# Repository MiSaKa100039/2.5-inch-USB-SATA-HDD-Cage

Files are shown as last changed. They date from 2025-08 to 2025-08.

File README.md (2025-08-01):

# ***2.5寸USB-SATA硬盘笼***

## <u>视频链接:[B站视频--功能演示及介绍](https://www.bilibili.com/video/BV1YCw5eoERG/?vd_source=5028cf5016d7ed990ad38551eb4883cf)</u>

## 项目简介:

本项目采用JMS578作为usb-sata桥,JMB575端口倍增的方案,实现usb到多个sata硬盘的通信

## 项目参数:

DC12v电源输入,jms578内置3.3v的ldo和buck控制器,因此只需考虑jmb575的3.3v和1.2v电压供电.
12v输入进来后通过tps54335a降压到5v,再使用mp9148双路buck降压输出3.3和1.2给jmb575供电

但是考虑到tps54335a的封装有点不好焊接,隧将其改为了中兴zxdn10的电源模块
和主机间连接采用Type-B接口,相对来说更为牢固.接口速度为USB3.0 5Gpbs,但是usb后面级联sata的方案对于硬盘的随机读写性能有较大的损失,所以对此在意的可以考虑其他方案(机械硬盘用户无视此条)







## 注意事项

1.在usb接口和dc电源接口的地方,请用钳子剪掉突出来的引脚,避免接触到硬盘.
2.先焊接电源部分,上电电压正常后再焊接芯片,以免烧毁芯片
3.jms578的晶振为30mhz,jmb575为25mhz
4.固件默认休眠时间为10min,若需更长时间或者关闭休眠,可以使用附件中的软件修改
5.由于最后一次修改工程后没能保存,所以附件中的ib0m和实际有区别,就是风扇接口位置不同.
6.电源功率的大小取决于你的硬盘功率
7.flash大部分都兼容,不确定就买p25d40h,便宜好用.



## 组装流程

背后的散热风扇为12v5010的风扇,主板上有一颗电阻位,可以选择合适大小的电阻来调节风扇转速,一般情况下直接短接即可



## 实物图

















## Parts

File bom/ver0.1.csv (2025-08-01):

Comment | Description | Designator | Footprint | LibRef | Pins | Quantity | 编号
10uF |  | C1, C8, C15, C16, C19, C20, C40 | Capacitor_SMD:C_0603_1608Metric
0.1uF |  | C2, C9, C45 | Capacitor_SMD:C_0603_1608Metric
0.1uF |  | C3, C133 | Capacitor_SMD:C_0402_1005Metric
47uF |  | C4, C5, C13, C14 | Capacitor_SMD:C_0805_2012Metric
0.012uF |  | C6, C11 | Capacitor_SMD:C_0402_1005Metric
120pF |  | C7, C12 | Capacitor_SMD:C_0402_1005Metric
22uF |  | C17, C18 | Capacitor_SMD:C_0603_1608Metric
1uF |  | C21, C38, C57 | Capacitor_SMD:C_0402_1005Metric
33pF |  | C22, C31 | Capacitor_SMD:C_0603_1608Metric
100nF |  | C23, C24, C25, C26, C27, C28, C29, C30, C32, C33, C34, C46, C47, C50, C51, C52, C53, C54, C55, C56, C58, C59, C60, C61, C62, C63, C64, C65, C130, C131, C132 | Capacitor_SMD:C_0603_1608Metric
100nF |  | C35, C36 | Capacitor_SMD:C_0402_1005Metric
0R |  | C37, C39 | Capacitor_SMD:C_0402_1005Metric
10nF |  | C41, C42, C43, C44, C114, C115, C116, C117, C118, C119, C120, C121, C122, C123, C124, C125, C126, C127, C128, C129 | Capacitor_SMD:C_0402_1005Metric
25pF |  | C48, C49 | Capacitor_SMD:C_0603_1608Metric
270uF |  | C66, C67, C68, C69, C70, C71, C72, C73 | PCM_Capacitor_SMD_AKL:CP_Elec_6.3x5.4
220uF |  | C74, C75, C76, C77, C78, C79, C80, C81 | Capacitor_SMD:C_0805_2012Metric_Pad1.18x1.45mm_HandSolder
1uF |  | C82, C83, C84, C85, C86, C87, C88, C89 | Capacitor_SMD:C_0805_2012Metric_Pad1.18x1.45mm_HandSolder
100nF |  | C90, C91, C92, C93, C94, C95, C96, C97 | Capacitor_SMD:C_0805_2012Metric_Pad1.18x1.45mm_HandSolder
22uF |  | C98, C99, C100, C101, C102, C103, C104, C105 | PCM_Capacitor_SMD_AKL:CP_Elec_6.3x5.3
100uF |  | C106, C107, C108, C109, C110, C111, C112, C113 | Capacitor_SMD:C_0805_2012Metric_Pad1.18x1.45mm_HandSolder
LED |  | D1, D2, D3, D4, D5, D6, D7, D8 | LED_SMD:LED_0805_2012Metric
USB 3.1 B |  | J1 | Connector_USB:USB B 姣嶅骇 鐩寸珛
SWITCH |  | J2 | Connector_PinSocket_1.27mm:PinSocket_1x02_P1.27mm_Vertical
dc 5.5mm |  | J3 | Connector:DC socket 5.5mm
SATA纭洏鎻掑ご |  | J4, J5, J6, J7 | Connector_SATA_SAS:SATA 29pin smd
fan2 |  | J9 | Connector_PinSocket_1.27mm:PinSocket_1x02_P1.27mm_Vertical
~ |  | jmb1 | Package_DFN_QFN:QFN-64-1EP_9x9mm_P0.5mm_EP3.4x3.4mm_ThermalVias
15uH |  | L1, L2 | Inductor_SMD:L_Chilisin_BMRA00040420
1uH |  | L3 | Inductor_SMD:L_Chilisin_BMRA00040420
2uH |  | L4 | Inductor_SMD:L_Chilisin_BMRA00040420
4.7uH |  | L5 | Inductor_SMD:L_Chilisin_BMRA00040420
AO4407A |  | Q1, Q2 | PCM_4ms_Package_SOIC:SOIC-8_3.9x4.9mm_Pitch1.27mm
220k |  | R1, R8 | Resistor_SMD:R_0402_1005Metric
43.2K |  | R2, R9 | Resistor_SMD:R_0402_1005Metric
143K |  | R3, R10 | Resistor_SMD:R_0402_1005Metric
51.1R |  | R4, R12 | Resistor_SMD:R_0402_1005Metric
100k |  | R5, R13, R15, R21 | Resistor_SMD:R_0402_1005Metric
19.1K |  | R6, R14 | Resistor_SMD:R_0402_1005Metric
3.74K |  | R7, R11 | Resistor_SMD:R_0402_1005Metric
133k |  | R16, R22 | Resistor_SMD:R_0402_1005Metric
390k |  | R17 | Resistor_SMD:R_0402_1005Metric
402K |  | R18 | Resistor_SMD:R_0402_1005Metric
390K |  | R19 | Resistor_SMD:R_0402_1005Metric
88.7K |  | R20 | Resistor_SMD:R_0402_1005Metric
100K |  | R23 | Resistor_SMD:R_0402_1005Metric
330K |  | R24 | Resistor_SMD:R_0402_1005Metric
4.7K |  | R25, R29, R30, R31, R32 | Resistor_SMD:R_0402_1005Metric
12K |  | R26 | Resistor_SMD:R_0402_1005Metric
200R |  | R27 | Resistor_SMD:R_0603_1608Metric
12k |  | R28 | Resistor_SMD:R_0402_1005Metric
10k |  | R33 | Resistor_SMD:R_0402_1005Metric
4k |  | R34 | Resistor_SMD:R_0603_1608Metric
2k |  | R35, R36, R37, R38, R39, R40, R41, R42 | PCM_4ms_Resistor:R_0402
2k |  | R44 | PCM_4ms_Resistor:R_0603
T-BJT-NPN |  | T1 | Package_TO_SOT_SMD:SOT-23-3
TPS54335A |  | U1, U2 | Converter_DCDC:TPS54335ADRCR
~ |  | U3 | Package_TO_SOT_SMD:SOT-23-8
~ |  | U4, U6 | PCM_4ms_Package_SOIC:SOIC-8_3.9x4.9mm_Pitch1.27mm
~ |  | U5 | Package_DFN_QFN:QFN-48-1EP_6x6mm_P0.4mm_EP4.2x4.2mm_ThermalVias
Crystal_GND24_Small |  | Y1, Y2 | Crystal:Crystal_SMD_Abracon_ABM8AIG-4Pin_3.2x2.5mm

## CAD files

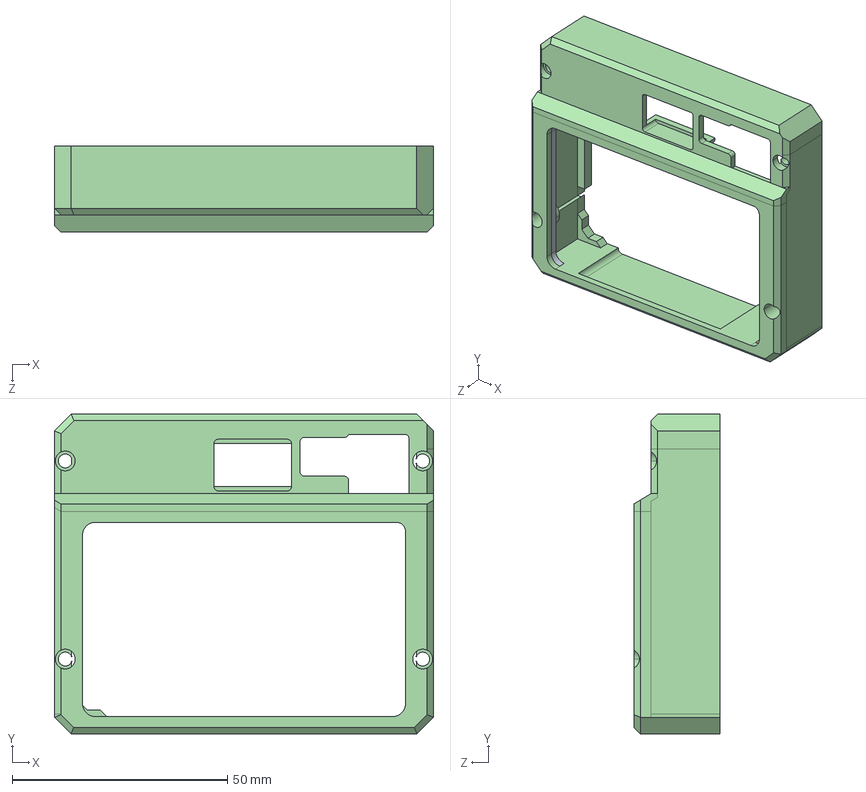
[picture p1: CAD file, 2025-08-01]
壳体/后盖v2.STEP
88.0 x 74.2 x 20.1 mm

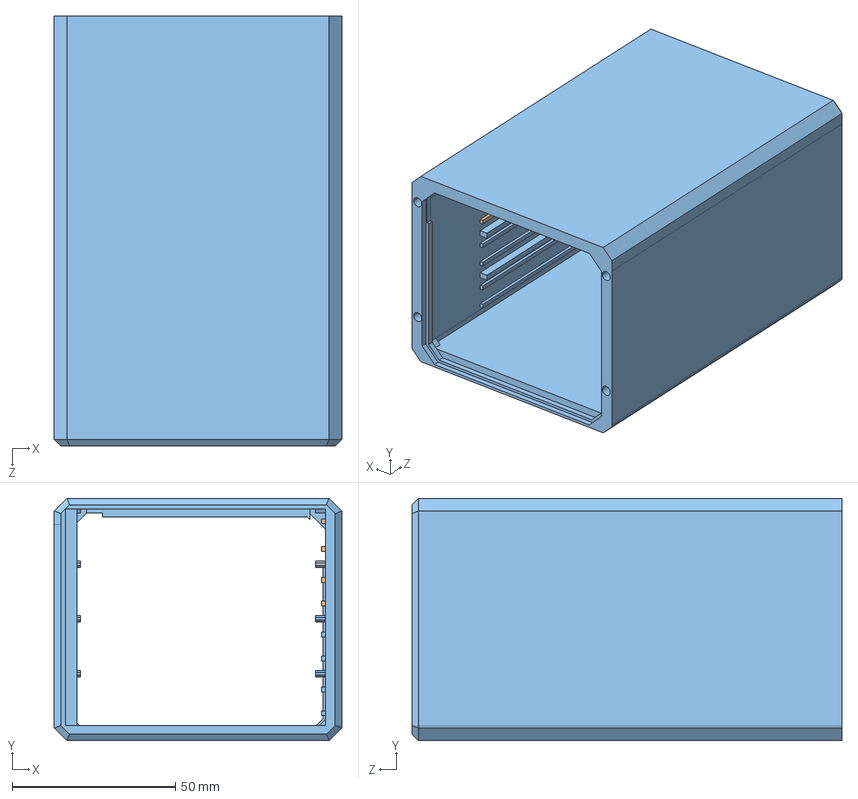
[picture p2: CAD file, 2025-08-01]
壳体/body.STEP
88.0 x 74.2 x 131.6 mm

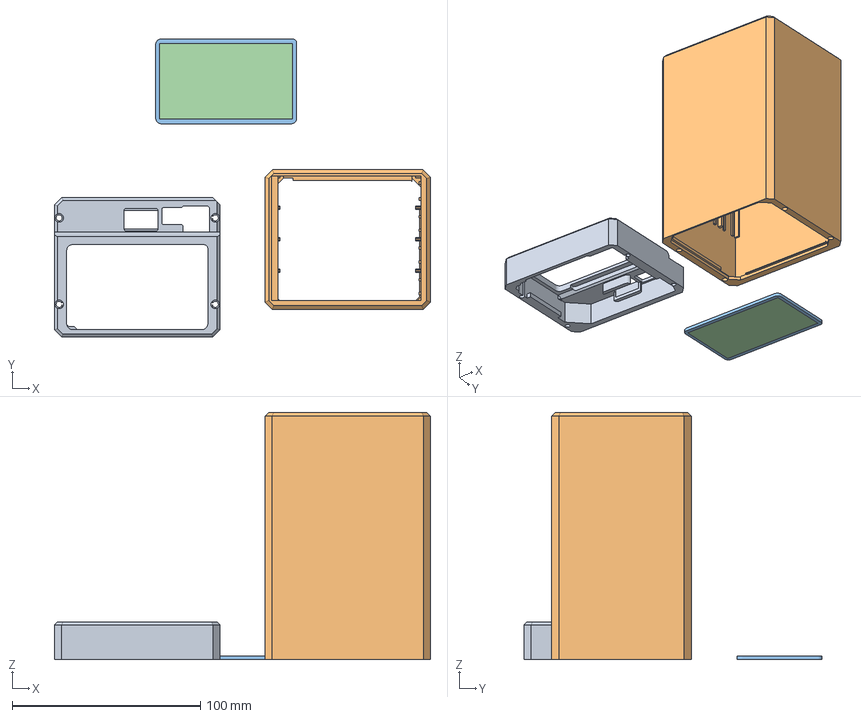
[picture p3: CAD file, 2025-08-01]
壳体/printer.3mf
199.9 x 158.5 x 131.6 mm
后盖v2.STEP
body.STEP
散热.STEP
立方体

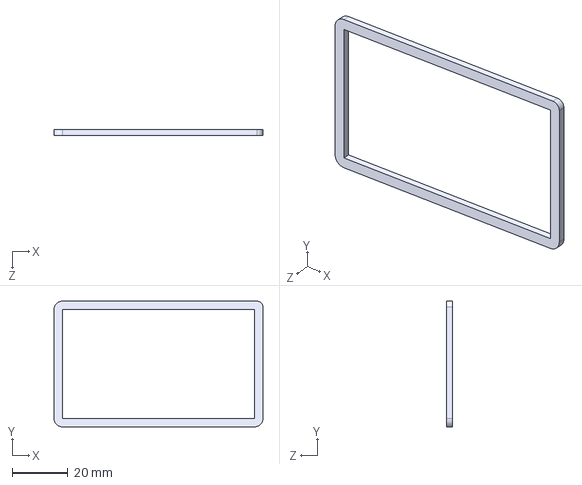
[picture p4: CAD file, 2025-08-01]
壳体/散热.STEP
75.0 x 45.1 x 2.00 mm

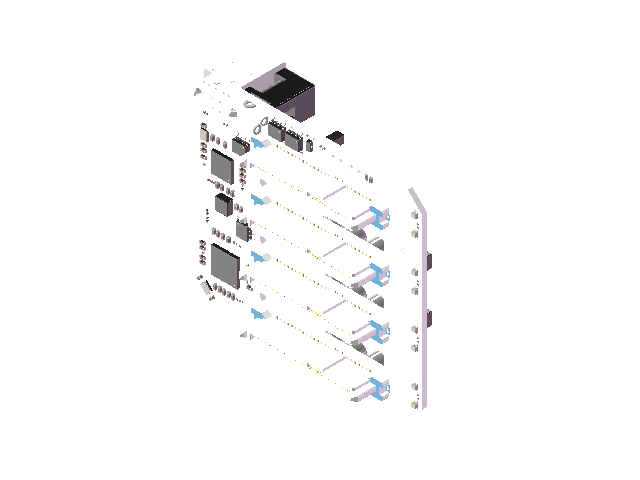
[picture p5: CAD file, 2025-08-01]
bord.SLDASM
SOLID.step x 42
SOLID-0.step x 8
SOLID-1.step x 8
SOLID-2.step x 47
SOLID-3.step x 33
SOLID-4.step x 4
SOLID-5.step
SOLID-6.step
SOLID-7.step
SOLID-8.step x 2
SOLID-9.step x 2
COMPOUND.step x 5
SOLID-10.step x 4
SOLID-11.step x 8
COMPOUND-12.step x 2
SOLID-13.step
SOLID-14.step x 8
COMPOUND-15.step
SOLID-16.step
COMPOUND-17.step
ver0.1 PCB.step

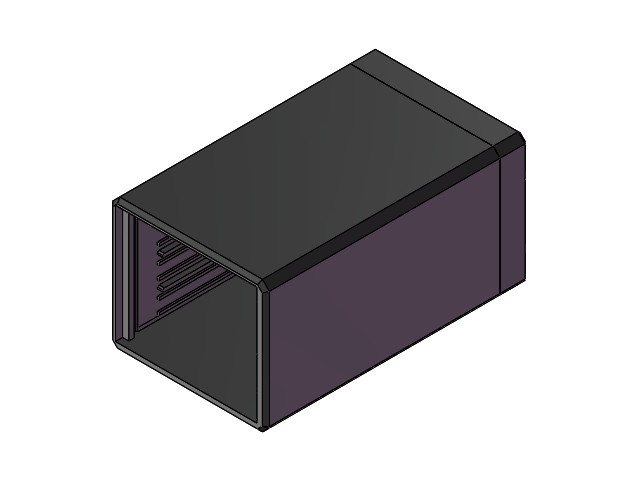
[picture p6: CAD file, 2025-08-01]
壳体/v0.1.SLDASM
零件1^装配体1
零件2^装配体1

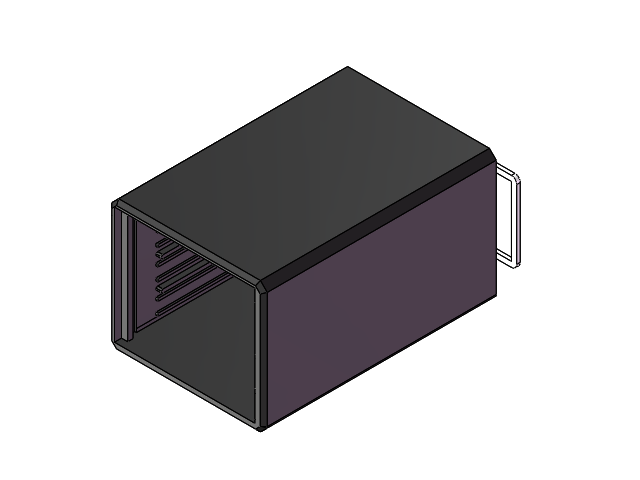
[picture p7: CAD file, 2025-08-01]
壳体/ve0.2.SLDASM
零件1^ve0.2
零件5^ve0.2

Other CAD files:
壳体/后盖.STEP

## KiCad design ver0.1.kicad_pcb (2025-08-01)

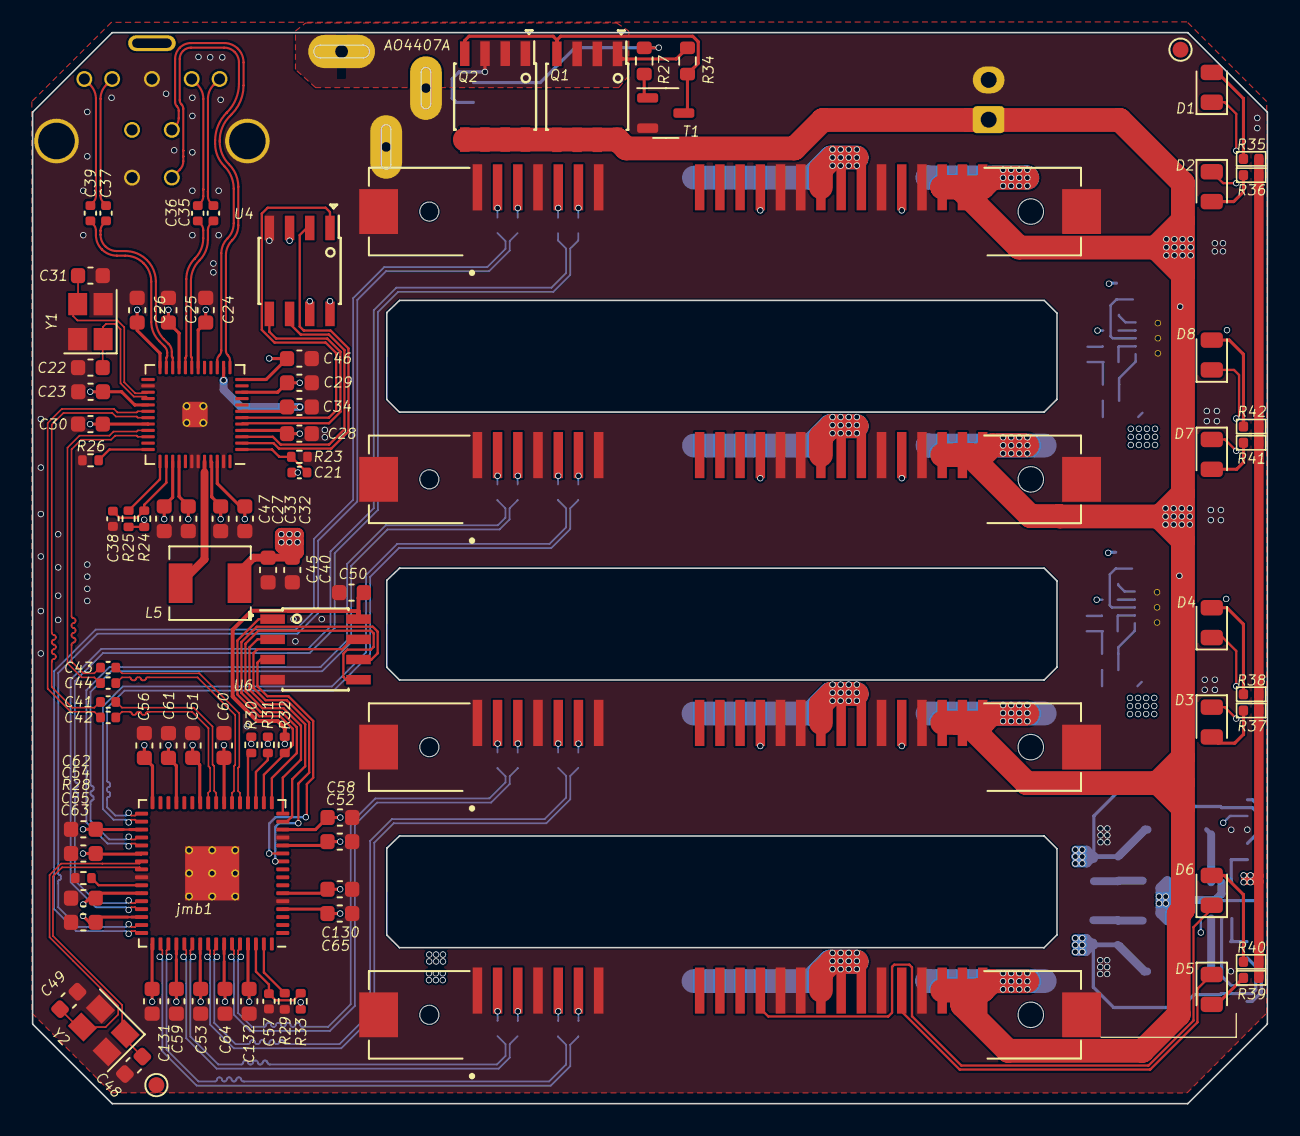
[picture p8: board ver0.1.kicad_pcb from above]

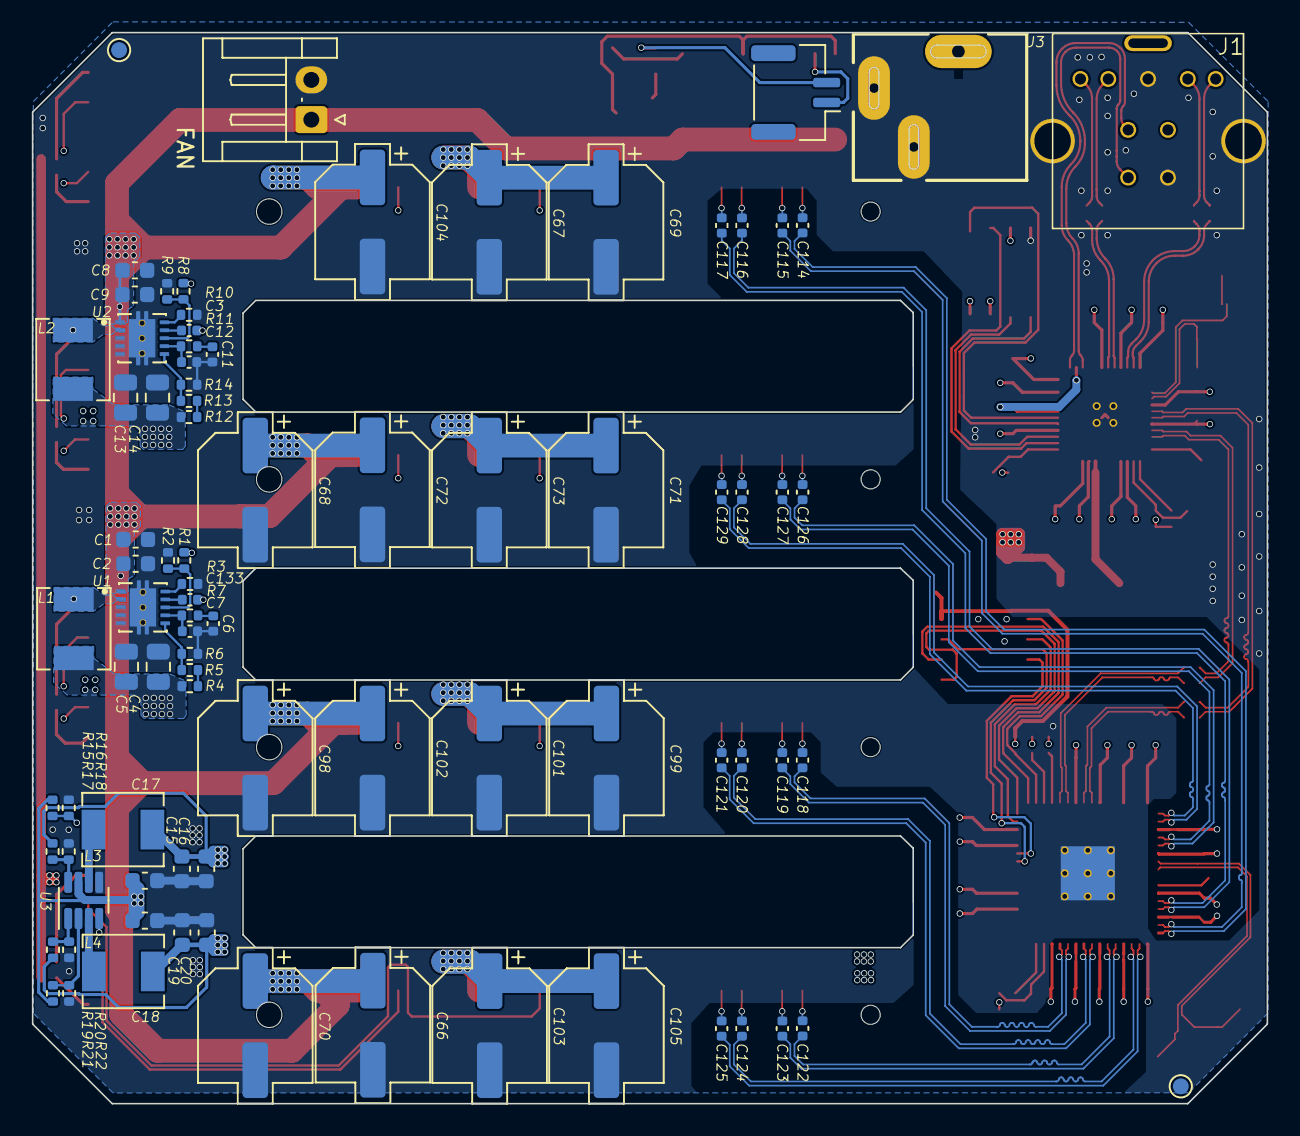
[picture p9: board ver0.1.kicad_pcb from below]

Board: 4 copper layers, 77.6 x 67.3 mm, 178 parts (86 on the bottom side), 124 nets.

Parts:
C1, C8, C15, C16, C19, C20, C40: 10uF; C_0603_1608Metric
C2, C9, C45: 0.1uF; C_0603_1608Metric
C3, C133: 0.1uF; C_0402_1005Metric
C4, C5, C13, C14: 47uF; C_0805_2012Metric
C6, C11: 0.012uF; C_0402_1005Metric
C7, C12: 120pF; C_0402_1005Metric
C17, C18: 22uF; C_0603_1608Metric
C21, C38, C57: 1uF; C_0402_1005Metric
C22, C31: 33pF; C_0603_1608Metric
C23, C24, C25, C26, C27, C28, C29, C30, C32, C33, C34, C46, C47, C50, C51, C52, C53, C54, C55, C56, C58, C59, C60, C61, C62, C63, C64, C65, C130, C131, C132: 100nF; C_0603_1608Metric
C35, C36: 100nF; C_0402_1005Metric
C37, C39: 0R; C_0402_1005Metric
C41, C42, C43, C44, C114, C115, C116, C117, C118, C119, C120, C121, C122, C123, C124, C125, C126, C127, C128, C129: 10nF; C_0402_1005Metric
C48, C49: 25pF; C_0603_1608Metric
C66, C67, C68, C69, C70, C71, C72, C73: 270uF; CP_Elec_6.3x5.4
C98, C99, C101, C102, C103, C104, C105: 22uF; CP_Elec_6.3x5.3
D1, D2, D3, D4, D5, D6, D7, D8: LED; LED_0805_2012Metric
FAN: fan2; JST_EH_S2B-EH_1x02_P2.50mm_Horizontal
FID1, FID2, FID3, FID4: Fiducial; TestPoint_Pad_D1.0mm
J1: USB 3.1 B; USB B 母座 直立
J2: SWITCH; JST_GH_BM02B-GHS-TBT_1x02-1MP_P1.25mm_Vertical
J3: dc 5.5mm; DC socket 5.5mm
J4, J5, J6, J7: SATA硬盘插头; SATA 29pin smd
L1, L2: 15uH; L_Chilisin_BMRA00040420
L3: 1uH; L_Chilisin_BMRA00040420
L4: 2uH; L_Chilisin_BMRA00040420
L5: 4.7uH; L_Chilisin_BMRA00040420
Q1, Q2: AO4407A; SOIC-8_3.9x4.9mm_Pitch1.27mm
R1, R8: 220k; R_0402_1005Metric
R2, R9: 43.2K; R_0402_1005Metric
R3, R10: 143K; R_0402_1005Metric
R4, R12: 51.1R; R_0402_1005Metric
R5, R13, R15, R21: 100k; R_0402_1005Metric
R6, R14: 19.1K; R_0402_1005Metric
R7, R11: 3.74K; R_0402_1005Metric
R16, R22: 43k; R_0402_1005Metric
R17, R19: 600K; R_0402_1005Metric
R18: 712K; R_0402_1005Metric
R20: 140K; R_0402_1005Metric
R23: 100K; R_0402_1005Metric
R24: 330K; R_0402_1005Metric
R25, R29, R30, R31, R32: 4.7K; R_0402_1005Metric
R26: 12K; R_0402_1005Metric
R27: 200Re; R_0603_1608Metric
R28: 12k; R_0402_1005Metric
R33: 10k; R_0402_1005Metric
R34: 4k; R_0603_1608Metric
R35, R36, R37, R38, R39, R40, R41, R42: 2k; R_0402
T1: T-BJT-NPN; SOT-23-3
U1, U2: TPS54335A; TPS54335ADRCR
U3: SOT-23-8
U4, U6: SOIC-8_3.9x4.9mm_Pitch1.27mm
U5: QFN-48-1EP_6x6mm_P0.4mm_EP4.2x4.2mm_ThermalVias
Y1, Y2: Crystal_GND24_Small; Crystal_SMD_Abracon_ABM8AIG-4Pin_3.2x2.5mm
jmb1: QFN-64-1EP_9x9mm_P0.5mm_EP3.4x3.4mm_ThermalVias

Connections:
+1V2: C15.2, C16.2, C58.2, C59.2, C60.2, C61.2, C62.2, C63.2, C64.2, C65.2, L3.1, R17.2, jmb1.4 (DV1.2), jmb1.14 (DV1.2), jmb1.23 (AV1.2), jmb1.29 (AV1.2), jmb1.35 (AV1.2), jmb1.46 (AV1.2), jmb1.52 (AV1.2), jmb1.58 (AV1.2)
+3V3: C19.2, C20.2, C50.2, C51.2, C52.2, C53.2, C54.2, C55.2, C56.2, C130.2, C131.2, C132.2, L4.2, R19.2, R30.2, R31.2, R32.2, R33.2, R35.1, R36.1, R37.1, R38.1, R39.1, R40.1, R41.1, R42.1, U6.8 (VCC), jmb1.6 (DV3.3), jmb1.12 (DV3.3), jmb1.26 (AV3.3), jmb1.32 (AV3.3), jmb1.38 (AV3.3), jmb1.43 (AV3.3), jmb1.49 (AV3.3), jmb1.55 (AV3.3), jmb1.61 (AV3.3)
+5V: C4.1, C5.1, C13.1, C14.1, C17.2, C18.2, C67.1, C69.1, C71.1, C73.1, C99.1, C101.1, C103.1, C105.1, J4.P7, J4.P8, J4.P9, J5.P7, J5.P8, J5.P9, J6.P7, J6.P8, J6.P9, J7.P7, J7.P8, J7.P9, L1.2, L2.2, R4.1, R12.1, R15.2, R21.2, U3.7 (IN)
/AGPIO0: U6.6 (SCLK), jmb1.17 (ZGPIO0)
/AGPIO1: U6.5 (SI), jmb1.16 (ZGPIO1)
/AGPIO2: U6.2 (SO), jmb1.15 (ZGPIO2)
/AGPIO3: U6.3 (WP#), jmb1.11 (ZGPIO3)
/AGPIO4: U6.7 (HOLD#), jmb1.10 (ZGPIO4)
/AGPIO12: R29.1, jmb1.63 (ZGPIO12)
/AGPIO13: R31.1, jmb1.19 (ZGPIO13)
/AGPIO14: R32.1, U6.1 (CS#), jmb1.18 (ZGPIO14)
/ARESETn: C57.1, R33.1, jmb1.62 (XRSTN)
/AREXT: R28.1, jmb1.42 (AREXT)
/ARXN0: C116.2, jmb1.45 (ARXN0)
/ARXN1: C120.2, jmb1.57 (ARXN1)
/ARXN2: C124.2, jmb1.51 (ARXN2)
/ARXN3: C128.2, jmb1.34 (ARXN3)
/ARXP0: C117.2, jmb1.44 (ARXP0)
/ARXP1: C121.2, jmb1.56 (ARXP1)
/ARXP2: C125.2, jmb1.50 (ARXP2)
/ARXP3: C129.2, jmb1.33 (ARXP3)
/ATESTn: R30.1, jmb1.20 (XTSTN)
/ATXN0: C115.2, jmb1.47 (ATXN0)
/ATXN1: C119.2, jmb1.59 (ATXN1)
/ATXN2: C123.2, jmb1.53 (ATXN2)
/ATXN3: C127.2, jmb1.36 (ATXN3)
/ATXP0: C114.2, jmb1.48 (ATXP0)
/ATXP1: C118.2, jmb1.60 (ATXP1)
/ATXP2: C122.2, jmb1.54 (ATXP2)
/ATXP3: C126.2, jmb1.37 (ATXP3)
/AXIN: C49.1, Y2.3, jmb1.39 (AXIN)
/AXOUT: C48.2, Y2.1, jmb1.40 (AXOUT)
/DAS1: D2.1 (K), J4.P11
/DAS2: D3.1 (K), J5.P11
/DAS3: D5.1 (K), J6.P11
/DAS4: D7.1 (K), J7.P11
/GPIO0: U4.2 (SO), U5.2 (GPIO0)
/GPIO1: U4.6 (SCLK), U5.3 (GPIO1)
/GPIO2: U4.5 (SI), U5.5 (GPIO2)
/GPIO3: U4.1 (CS#), U5.6 (GPIO3)
/HOT1: D1.1 (K), J4.P4
/HOT2: D4.1 (K), J5.P4
/HOT3: D6.1 (K), J6.P4
/HOT4: D8.1 (K), J7.P4
/HSD0+: J1.3 (D+), U5.15 (DP)
/HSD0-: J1.2 (D-), U5.13 (DM)
/LXO: L5.1, U5.44 (LXO)
/RST: C38.1, R24.2, U5.38 (RST#)
/RX_N: C41.1, U5.31 (RXN)
/RX_P: C42.1, U5.30 (RXP)
/SSRX0+: C39.1, J1.9 (STDB_SSRX+)
/SSRX0-: C37.1, J1.8 (STDB_SSRX-)
/SSTX0+: C35.1, J1.5 (STDB_SSTX-)
/SSTX0-: C36.1, J1.6 (STDB_SSTX+)
/TX_N: C44.1, U5.33 (TXN)
/TX_P: C43.1, U5.34 (TXP)
/XIN: C22.2, U5.28 (XIN), Y1.1
/XOUT: C31.1, U5.27 (XOUT), Y1.3
/cap-SSRX1+: C39.2, U5.23 (SSRXP)
/cap-SSRX1-: C37.2, U5.22 (SSRXN)
/cap-SSTX1+: C36.2, U5.20 (SSTXP)
/cap-SSTX1-: C35.2, U5.19 (SSTXN)
/net-RX_N: C41.2, jmb1.24 (ATXN5)
/net-RX_P: C42.2, jmb1.25 (ATXP5)
/net-TX_N: C44.2, jmb1.22 (ARXN5)
/net-TX_P: C43.2, jmb1.21 (ARXP5)
/vout1.2: C23.2, C24.2, C25.2, C26.2, C27.2, C28.2, C29.2, C30.2, C40.2, C45.2, L5.2, U5.4 (VCCK), U5.10 (VCCK), U5.18 (AVDDL), U5.21 (AVDDL), U5.24 (AVDDL), U5.29 (AVDDL), U5.32 (AVDDL), U5.40 (VCCK)
/vout3.3: C21.1, C32.2, C33.2, C34.2, R24.1, R25.2, U4.3 (WP#), U4.7 (HOLD#), U4.8 (VCC), U5.7 (VCCO), U5.14 (AV33O), U5.39 (VCCO), U5.46 (MODE0)
GND: C1.1, C2.1, C4.2, C5.2, C6.2, C7.2, C8.1, C9.1, C11.2, C12.2, C13.2, C14.2, C15.1, C16.1, C17.1, C18.1, C19.1, C20.1, C22.1, C23.1, C24.1, C25.1, C26.1, C27.1, C28.1, C29.1, C30.1, C31.2, C32.1, C33.1, C34.1, C38.2, C40.1, C45.1, C46.1, C47.1, C48.1, C49.2, C50.1, C51.1, C52.1, C53.1, C54.1, C55.1, C56.1, C57.2, C58.1, C59.1, C60.1, C61.1, C62.1, C63.1, C64.1, C65.1, C66.2, C67.2, C68.2, C69.2, C70.2, C71.2, C72.2, C73.2, C98.2, C99.2, C101.2, C102.2, C103.2, C104.2, C105.2, C130.1, C131.1, C132.1, FAN.2, J1.4 (GND), J1.7 (GND_DRAIN), J1.S1, J1.S2, J3.2, J3.3, J4.P5, J4.P6, J4.P10, J4.P12, J4.S1, J4.S4, J4.S7, J4.SH1 (SHIELD), J4.SH2 (SHIELD), J5.P5, J5.P6, J5.P10, J5.P12, J5.S1, J5.S4, J5.S7, J5.SH1 (SHIELD), J5.SH2 (SHIELD), J6.P5, J6.P6, J6.P10, J6.P12, J6.S1, J6.S4, J6.S7, J6.SH1 (SHIELD), J6.SH2 (SHIELD), J7.P5, J7.P6, J7.P10, J7.P12, J7.S1, J7.S4, J7.S7, J7.SH1 (SHIELD), J7.SH2 (SHIELD), R2.2, R3.2, R6.2, R9.2, R10.2, R14.2, R16.1, R18.1, R20.1, R22.1, R23.2, R26.2, R28.2, R29.2, T1.2 (B), U1.3 (GND), U1.4 (GND), U1.5 (GND), U1.11 (GND), U2.3 (GND), U2.4 (GND), U2.5 (GND), U2.11 (GND), U3.5 (GND), U4.4 (GND), U5.26 (NC), U5.42 (MODE1), U5.43 (GND), U5.47 (NC), U5.49 (GND), U6.4 (GND), Y1.2, Y1.4, Y2.2, Y2.4, jmb1.5 (DGND), jmb1.13 (DGND), jmb1.41 (AGND), jmb1.65 (GND)
unnamed: C6.1, R7.2
unnamed: C11.1, R11.2
unnamed: C114.1, J4.S2
unnamed: C115.1, J4.S3
unnamed: C116.1, J4.S5
unnamed: C117.1, J4.S6
unnamed: C118.1, J5.S2
unnamed: C119.1, J5.S3
unnamed: C120.1, J5.S5
unnamed: C121.1, J5.S6
unnamed: C122.1, J6.S2
unnamed: C123.1, J6.S3
unnamed: C124.1, J6.S5
unnamed: C125.1, J6.S6
unnamed: C126.1, J7.S2
unnamed: C127.1, J7.S3
unnamed: C128.1, J7.S5
unnamed: C129.1, J7.S6
unnamed: D1.2 (A), R35.2
unnamed: D2.2 (A), R36.2
unnamed: D3.2 (A), R37.2
unnamed: D4.2 (A), R38.2
unnamed: D5.2 (A), R39.2
unnamed: D6.2 (A), R40.2
unnamed: D7.2 (A), R41.2
unnamed: D8.2 (A), R42.2
unnamed: J2.2, R27.1
unnamed: Q1.4 (G), Q2.4 (G), R34.2, T1.3 (E)
unnamed: R4.2, R5.1
unnamed: R12.2, R13.1
unnamed: R27.2, T1.1 (C)
unnamed: C133.1, U1.9 (BOOT)
unnamed: C7.1, R7.1, U1.7 (COMP)
unnamed: R1.2, R2.1, U1.8 (EN)
unnamed: C133.2, L1.1, U1.2 (PH)
unnamed: R3.1, U1.10 (RT)
unnamed: C3.1, U2.9 (BOOT)
unnamed: C12.1, R11.1, U2.7 (COMP)
unnamed: R8.2, R9.1, U2.8 (EN)
unnamed: C3.2, L2.1, U2.2 (PH)
unnamed: R10.1, U2.10 (RT)
unnamed: R15.1, R16.2, U3.4 (EN1)
unnamed: R21.1, R22.2, U3.2 (EN2)
unnamed: R17.1, R18.2, U3.8 (FB1)
unnamed: R19.1, R20.2, U3.1 (FB2)
unnamed: L3.2, U3.6 (SW1)
unnamed: L4.1, U3.3 (SW2)
unnamed: R26.1, U5.36 (REXT)
unnamed: C21.2, R23.1, U5.1 (TME)
unnamed: R25.1, U5.37 (UAO/GPIO8)
VBUS: C46.2, C47.2, J1.1 (VBUS), U5.12 (VBUS), U5.45 (VREG_IN)
VDC: J2.1, J3.1, Q1.1 (S), Q1.2 (S), Q1.3 (S), Q2.1 (S), Q2.2 (S), Q2.3 (S), R34.1
Vin_12V: C1.2, C2.2, C8.2, C9.2, C66.1, C68.1, C70.1, C72.1, C98.1, C102.1, C104.1, FAN.1, J4.P13, J4.P14, J4.P15, J5.P13, J5.P14, J5.P15, J6.P13, J6.P14, J6.P15, J7.P13, J7.P14, J7.P15, Q1.5 (D), Q1.6 (D), Q1.7 (D), Q1.8 (D), Q2.5 (D), Q2.6 (D), Q2.7 (D), Q2.8 (D), R1.1, R8.1, U1.1 (VIN), U2.1 (VIN)
Vsense-A: R5.2, R6.1, U1.6 (VSENSE)
Vsense-B: R13.2, R14.1, U2.6 (VSENSE)
